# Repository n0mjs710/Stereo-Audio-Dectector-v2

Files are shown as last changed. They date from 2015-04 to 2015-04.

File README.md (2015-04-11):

# Stereo-Audio-Dectector-v2

Stereo Audio Detector: Precision rectifiers and integrators for driving VU displays.

This analog cirucit is intended to handle "front-end" conditioning for VU meters, but could be used for any low-frequency analog AC signal where the envelope of the waveform is of interest. The schmatic has several notes for changing values for different purposes.

The original intention was as VU meter front-end for Arduino or Teensy microcontrollers to use to "talk" to the Stereo VU Meter display, also published under my github account.

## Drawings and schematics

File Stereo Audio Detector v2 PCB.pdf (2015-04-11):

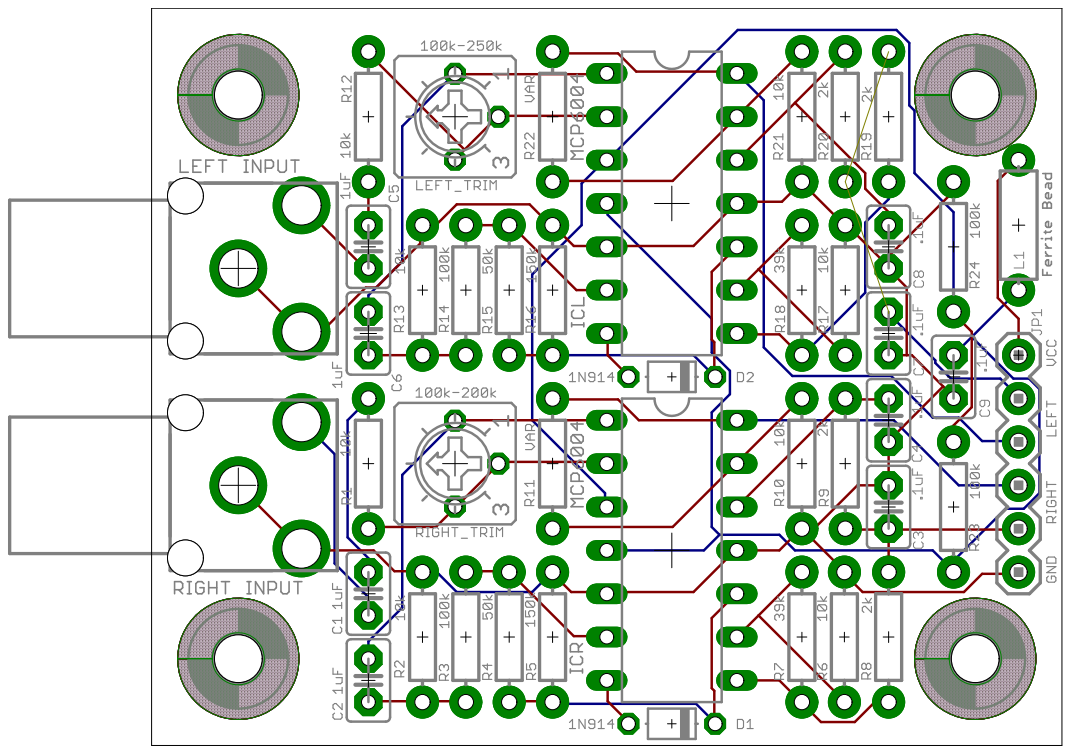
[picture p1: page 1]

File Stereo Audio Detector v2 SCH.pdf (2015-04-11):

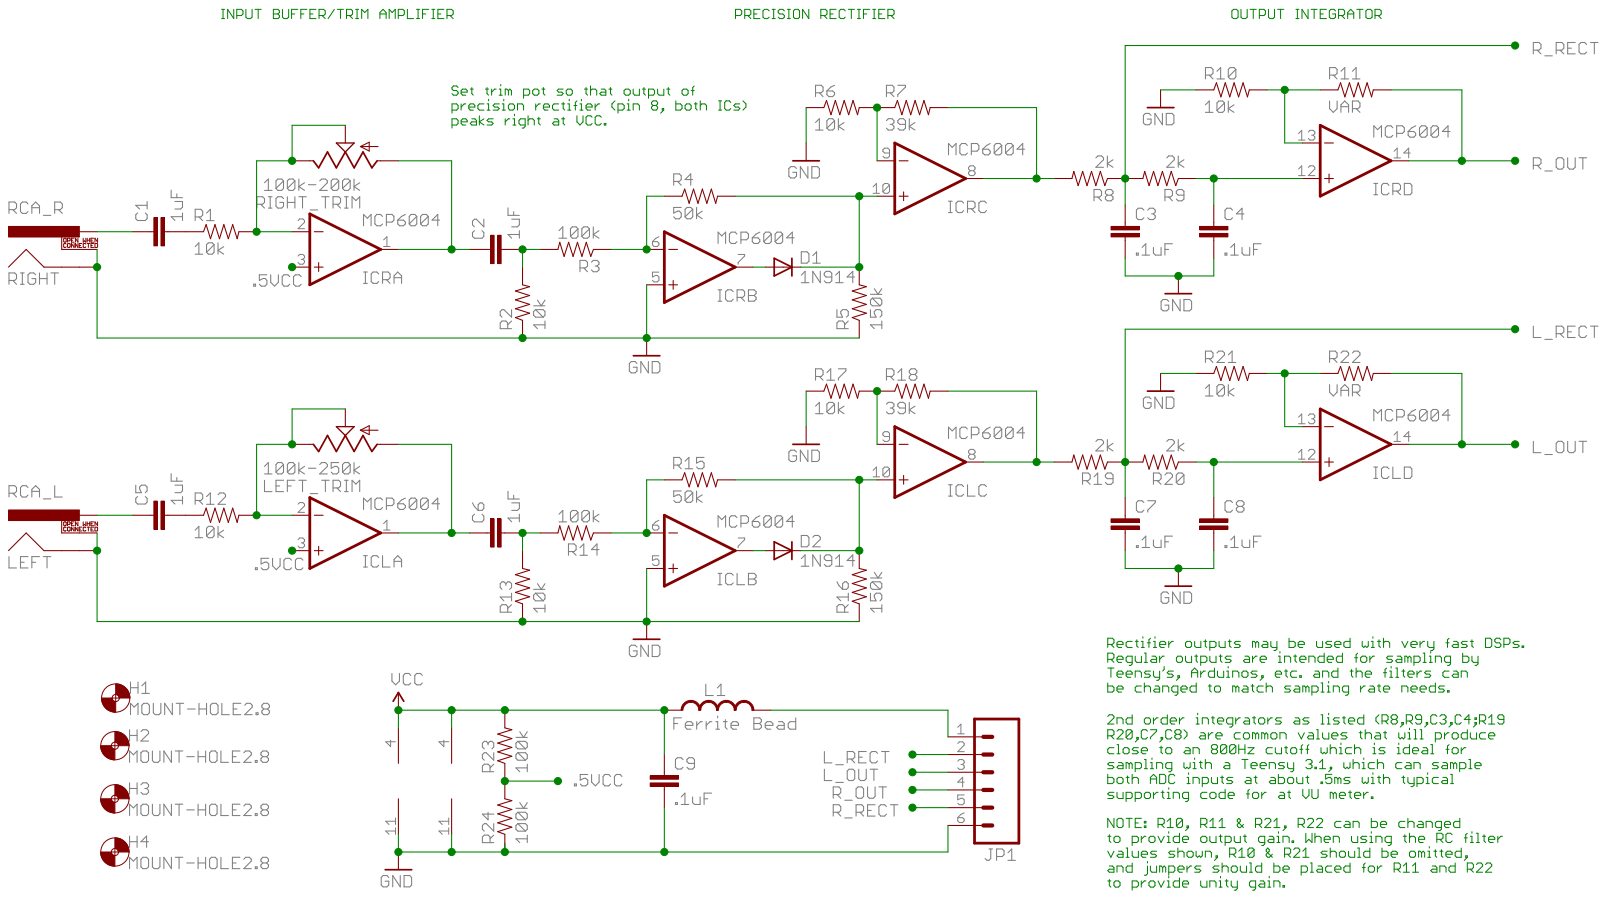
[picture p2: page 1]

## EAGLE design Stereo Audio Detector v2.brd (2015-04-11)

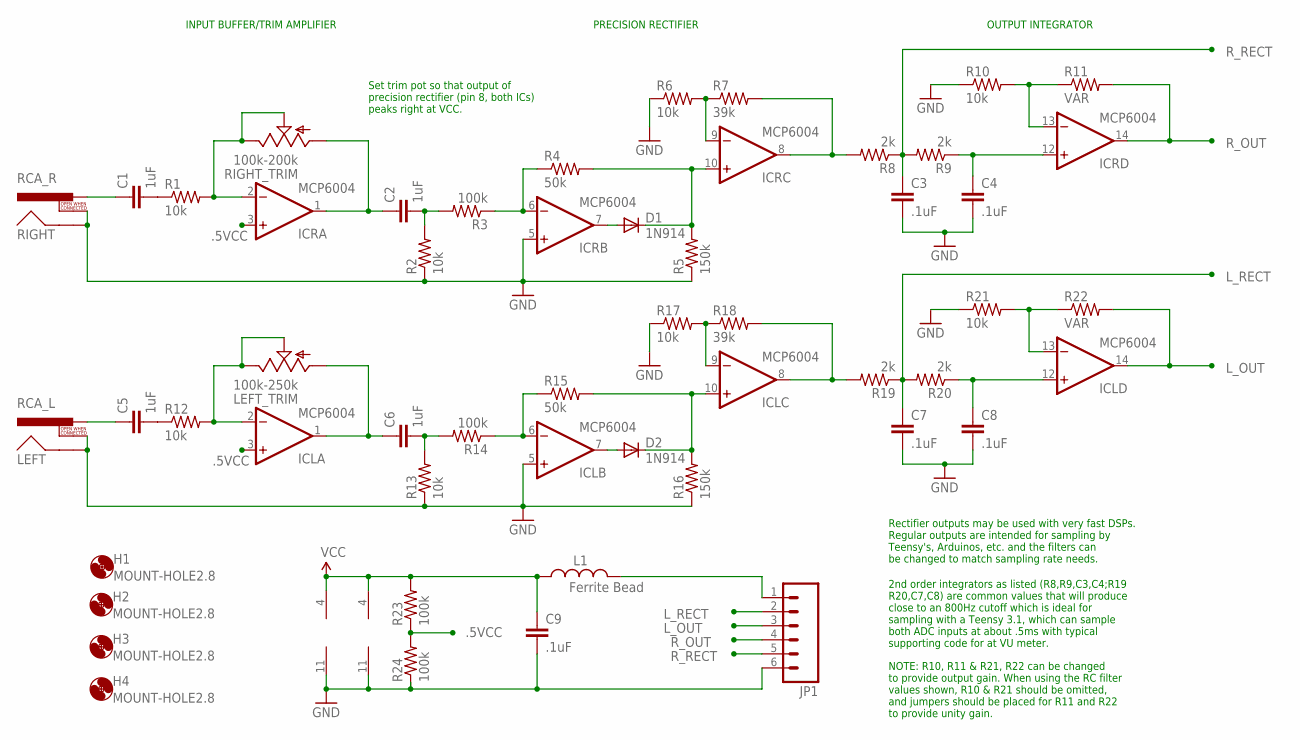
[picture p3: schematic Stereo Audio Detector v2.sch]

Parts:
C1, C2, C5, C6: 1uF; C2.5-2
C3, C4, C7, C8, C9: .1uF; C2.5-2
D1, D2: 1N914; D-5
H1, H2, H3, H4: MOUNT-HOLE2.8; 2,8
ICL: MCP6004; DIL14
ICR: MCP6004; DIL14
JP1: M06SIP; 1X06
L1: Ferrite Bead; AXIAL-0.3
LEFT: RCA_L; RCA
LEFT_TRIM: 100k-250k; CT6
R1, R2, R6, R10, R12, R13, R17, R21: 10k; AXIAL-0.3
R3, R14, R23, R24: 100k; AXIAL-0.3
R4, R15: 50k; AXIAL-0.3
R5, R16: 150k; AXIAL-0.3
R7, R18: 39k; AXIAL-0.3
R8, R9, R19, R20: 2k; AXIAL-0.3
R11, R22: VAR; AXIAL-0.3
RIGHT: RCA_R; RCA
RIGHT_TRIM: 100k-200k; CT6

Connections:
.5VCC: ICL.3 (+IN), ICR.3 (+IN), R23.P$1 (1), R24.P$2 (2)
GND: C3.2, C4.2, C7.2, C8.2, C9.2, ICL.5 (+IN), ICL.11 (V-), ICR.5 (+IN), ICR.11 (V-), JP1.6, LEFT.SHELL, LEFT.SWITCH, R2.P$1 (1), R5.P$1 (1), R6.P$1 (1), R10.P$1 (1), R13.P$1 (1), R16.P$1 (1), R17.P$1 (1), R21.P$1 (1), R24.P$1 (1), RIGHT.SHELL, RIGHT.SWITCH
IN_L: C1.1, RIGHT.PIN
IN_R: C5.1, LEFT.PIN
L_OUT: ICL.14 (OUT), JP1.3, R22.P$2 (2)
L_RECT: C7.1, JP1.2, R19.P$1 (1), R20.P$2 (2)
unnamed: C5.2, R12.P$1 (1)
unnamed: C1.2, R1.P$1 (1)
unnamed: JP1.1, L1.P$2 (2)
unnamed: ICR.2 (-IN), R1.P$2 (2), RIGHT_TRIM.E, RIGHT_TRIM.S
unnamed: C2.2, R2.P$2 (2), R3.P$2 (2)
unnamed: C2.1, ICR.1 (OUT), RIGHT_TRIM.A
unnamed: ICL.2 (-IN), LEFT_TRIM.E, LEFT_TRIM.S, R12.P$2 (2)
unnamed: ICR.6 (-IN), R3.P$1 (1), R4.P$1 (1)
unnamed: D1.C, ICR.10 (+IN), R4.P$2 (2), R5.P$2 (2)
unnamed: ICR.8 (OUT), R7.P$2 (2), R8.P$2 (2)
unnamed: ICR.9 (-IN), R6.P$2 (2), R7.P$1 (1)
unnamed: D1.A, ICR.7 (OUT)
unnamed: C4.1, ICR.12 (+IN), R9.P$1 (1)
unnamed: ICR.13 (-IN), R10.P$2 (2), R11.P$1 (1)
unnamed: C6.1, ICL.1 (OUT), LEFT_TRIM.A
unnamed: C6.2, R13.P$2 (2), R14.P$2 (2)
unnamed: ICL.6 (-IN), R14.P$1 (1), R15.P$1 (1)
unnamed: ICL.9 (-IN), R17.P$2 (2), R18.P$1 (1)
unnamed: ICL.8 (OUT), R18.P$2 (2), R19.P$2 (2)
unnamed: D2.A, ICL.7 (OUT)
unnamed: D2.C, ICL.10 (+IN), R15.P$2 (2), R16.P$2 (2)
unnamed: ICL.13 (-IN), R21.P$2 (2), R22.P$1 (1)
unnamed: C8.1, ICL.12 (+IN), R20.P$1 (1)
R_OUT: ICR.14 (OUT), JP1.4, R11.P$2 (2)
R_RECT: C3.1, JP1.5, R8.P$1 (1), R9.P$2 (2)
VCC: C9.1, ICL.4 (V+), ICR.4 (V+), L1.P$1 (1), R23.P$2 (2)

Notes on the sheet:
NOTE: R10, R11 & R21, R22 can be changed to provide output gain. When using the RC filter values shown, R10 & R21 should be omitted, and jumpers should be placed for R11 and R22 to provide unity gain.
2nd order integrators as listed (R8,R9,C3,C4;R19 R20,C7,C8) are common values that will produce close to an 800Hz cutoff which is ideal for sampling with a Teensy 3.1, which can sample both ADC inputs at about .5ms with typical supporting code for at VU meter.
Rectifier outputs may be used with very fast DSPs. Regular outputs are intended for sampling by Teensy's, Arduinos, etc. and the filters can be changed to match sampling rate needs.
INPUT BUFFER/TRIM AMPLIFIER
PRECISION RECTIFIER
OUTPUT INTEGRATOR
Set trim pot so that output of precision rectifier (pin 8, both ICs) peaks right at VCC.

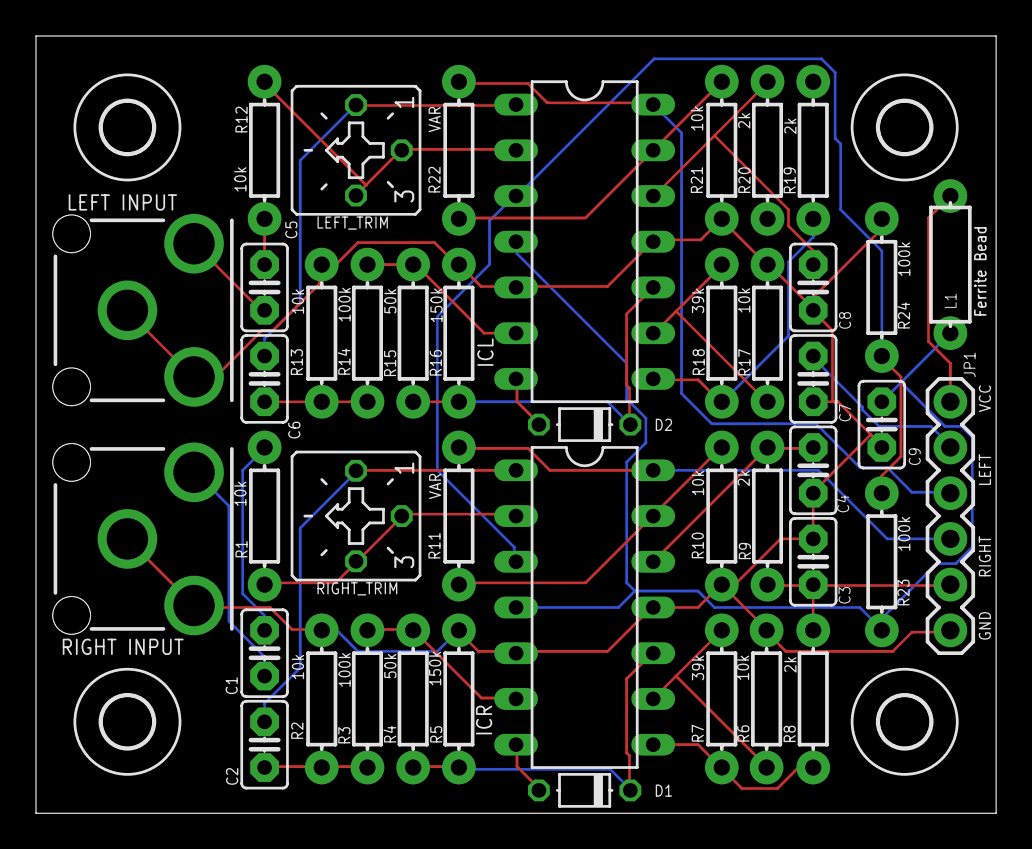
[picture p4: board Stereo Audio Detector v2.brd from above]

Board: 2 copper layers, 53.3 x 43.2 mm, 47 parts (0 on the bottom side), 32 nets.

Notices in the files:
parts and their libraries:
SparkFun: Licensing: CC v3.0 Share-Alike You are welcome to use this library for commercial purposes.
